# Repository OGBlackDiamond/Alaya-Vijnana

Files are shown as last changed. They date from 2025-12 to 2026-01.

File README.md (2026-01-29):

# Alaya-Vijnana
The hardware and software for my custom split ortholinear column-staggered keyboard
PCB Design Photo
Assembled PCB Photo

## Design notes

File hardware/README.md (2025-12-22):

# Alaya Vijnana Hardware

## B.O.M.
This is a complete B.O.M. for one half of the Alaya Vijnana's PCB components.

MCU:
* nRF52840 - [aQFN73](https://mm.digikey.com/Volume0/opasdata/d220001/medias/docus/6470/NRF52840-QFAA-F-R7.pdf)

Crystal Oscillators:
* 32MHz - [ECX-35B](https://ecsxtal.com/store/pdf/ecx_53b.pdf)
* 32.768kHz - [CM2012H](https://cfd.citizen.co.jp/cms/cfd/pdf/english/CM2012H_E.pdf)

Charger and Power:
* Charger - [BQ24075RGTR](https://www.digikey.com/en/products/detail/texas-instruments/BQ24075RGTR/2047273)
* Voltage Reg - [XC6220B331MR-G](https://www.digikey.com/en/products/detail/torex-semiconductor-ltd/XC6220B331MR-G/2138177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)

Battery Connector:
* JST PH - [S2B-PH-K-S](https://www.digikey.com/en/products/detail/jst-sales-america-inc/S2B-PH-K-S/926626)

Main to Cluster:
* 02x03 Header - 2 - [BHR-06-HUA](https://www.digikey.com/en/products/detail/adam-tech/BHR-06-HUA/10414833)
* Cable - 1 - [371](https://www.digikey.com/en/products/detail/adafruit-industries-llc/371/6827038)

Power Switch:
* E-Switch - [EG1224](https://www.digikey.com/en/products/detail/e-switch/EG1224/502052?s=N4IgTCBcDaIKIHEAEBGMYAsIC6BfIA)

USB-C Connector:
* USB CONN - [USB4085-GF-A](https://www.digikey.com/en/products/detail/gct/USB4085-GF-A/9859662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)

Inductors:
* 10uH - 2 - [MLZ1608M100WTD25](https://www.digikey.com/en/products/detail/tdk-corporation/MLZ1608M100WTD25/4743176)
* 15nH - 1 - [LRC0603CJ15NGV001T](https://www.digikey.com/en/products/detail/johanson-technology-inc/LRC0603CJ15NGV001T/1561308)
* 4.7nH - 1 - [LRC0603CS4N7GV001T](https://www.digikey.com/en/products/detail/johanson-technology-inc/LRC0603CS4N7GV001T/1561296)

LEDs:
* Charge - 1 - [HSMD-C150](https://www.digikey.com/en/products/detail/broadcom-limited/HSMD-C150/637702)

Diodes:
* 21 - [CDSU101A](https://www.digikey.com/en/products/detail/comchip-technology/CDSU101A/1121034)

Hot Swap Sockets:
* 2 (1 = 20pc) - [4958](https://www.digikey.com/en/products/detail/adafruit-industries-llc/4958/13997772)

Resistors:
* 10k - 3 - [RC0603FR-0710KL](https://www.digikey.com/en/products/detail/yageo/RC0603FR-0710KL/726880)
* 10M - 1 - [RC0603JR-0710ML](https://www.digikey.com/en/products/detail/yageo/RC0603JR-0710ML/726701)
* 5.1k - 2 - [RC0603FR-075K1L](https://www.digikey.com/en/products/detail/yageo/RC0603FR-075K1L/727268)
* 2k - 1 - [RC0603JR-072KL](https://www.digikey.com/en/products/detail/yageo/RC0603JR-072KL/726726https://www.digikey.com/en/products/detail/yageo/RC0603JR-072KL/726726)

Capacitors:
* 12pF - 4 - [0603N120J500CT](https://www.digikey.com/en/products/detail/walsin-technology-corporation/0603N120J500CT/9355484)
* 1uF - 3 - [TMK107B7105KA-T](https://www.digikey.com/en/products/detail/taiyo-yuden/TMK107B7105KA-T/2714162)
* 4.7uF - 8 - [C1608X5R1C475K080AC](https://www.digikey.com/en/products/detail/tdk-corporation/C1608X5R1C475K080AC/2732913)
* 0.8pF - 1 - [CC0603BRNPO9BNR80](https://www.digikey.com/en/products/detail/yageo/CC0603BRNPO9BNR80/11490491)
* 0.5pF - 1 - [CBR06C508B5GAC](https://www.digikey.com/en/products/detail/kemet/CBR06C508B5GAC/3473906)
* 10uF - 1 - [LMK107BBJ106MALT](https://www.digikey.com/en/products/detail/taiyo-yuden/LMK107BBJ106MALT/3662195)
* 100pF - 2 - [CC0603JRNPO9BN101](https://www.digikey.com/en/products/detail/yageo/CC0603JRNPO9BN101/302803)
* 820pF - 1 - [CC0603KRX7R9BB821](https://www.digikey.com/en/products/detail/yageo/CC0603KRX7R9BB821/372862)
* 0.047uF - 1 - [CC0603KRX7R8BB473](https://www.digikey.com/en/products/detail/yageo/CC0603KRX7R8BB473/2103111)
* 0.1uF - 3 - [CC0603KRX7R7BB104](https://www.digikey.com/en/products/detail/yageo/CC0603KRX7R7BB104/302822)

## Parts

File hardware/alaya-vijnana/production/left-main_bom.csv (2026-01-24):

Designator | Footprint | Quantity | Value | LCSC Part #
C1, C2, C23, C24 | 0603 | 4 | 12pF
C10, C11 | 0603 | 2 | 100pF
C12 | 0603 | 1 | 820pF
C13, C16, C17, C22, C25, C4, C5 | 0603 | 7 | 4.7uF
C14, C18, C3 | 0603 | 3 | 1uF
C15 | 0603 | 1 | 47nF
C19, C20, C21 | 0603 | 3 | 100nF
C6 | 0603 | 1 | 0.8pF
C7 | 0603 | 1 | 0.5pF
C8 | 0603 | 1 | N.C.
C9 | 0603 | 1 | 10uF
D1, D10, D11, D12, D13, D14, D15, D2, D3, D4, D5, D6, D7, D8, D9 | 0603 | 15 | D
J1 | JST_PH_S2B-PH-K_1x02_P2.00mm_Horizontal | 1 | Bat
J2 | USB_C_Receptacle_GCT_USB4085 | 1 | USB_C_Receptacle_USB2.0_16P
J5 | IDC-Header_2x03_P2.54mm_Horizontal | 1 | MAIN_CONN
L1 | 0402 | 1 | 4.7nH
L2, L4 | 0603 | 2 | 10uH
L3 | 0603 | 1 | 15nH
LED1 | 1206 | 1 | Charge_LED
R1 | 0603 | 1 | 2k
R2, R3, R4 | 0603 | 3 | 10k
R5 | 0603 | 1 | 10M
R6, R7 | 0603 | 2 | 5.1k
SW1 | SW_E-Switch_EG1224_SPDT_Angled | 1 | Power_Switch
SW10, SW11, SW12, SW13, SW14, SW15, SW16, SW2, SW3, SW4, SW5, SW6, SW7, SW8, SW9 | MX-Hotswap-1U | 15 | MX HotSwap
SW45 | SW_Push_1P1T_NO_CK_KMR2 | 1 | SW_Push
TP1 | 2816 | 1 | Charge Boost
U1 | Nordic_AQFN-73-1EP_7x7mm_P0.5mm | 1 | nRF52840
U2 | VQFN-16-1EP_3x3mm_P0.5mm_EP1.6x1.6mm | 1 | BQ24075RGT
U3 | SOT-23-5 | 1 | XC6220B331MR
X1 | Crystal_SMD_2012-2Pin_2.0x1.2mm | 1 | 32.768kHz
Y1 | Crystal_SMD_3225-4Pin_3.2x2.5mm_HandSoldering | 1 | 32Mhz

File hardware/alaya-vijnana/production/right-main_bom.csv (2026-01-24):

Designator | Footprint | Quantity | Value | LCSC Part #
C26, C39, C44 | 0603 | 3 | 1uf
C27, C28, C29 | 0603 | 3 | 100nF
C30, C36, C37, C38, C45, C46, C47 | 0603 | 7 | 4.7uF
C31, C32, C41, C42 | 0603 | 4 | 12pF
C33, C34 | 0603 | 2 | 100pF
C35 | 0603 | 1 | 820pF
C40 | 0603 | 1 | 47nF
C43 | 0603 | 1 | 10uF
C48 | 0603 | 1 | 0.8pF
C49 | 0603 | 1 | 0.5pF
C50 | 0603 | 1 | N.C.
D22, D23, D24, D25, D26, D27, D28, D29, D30, D31, D32, D33, D34, D35, D36 | 0603 | 15 | D
J3 | JST_PH_S2B-PH-K_1x02_P2.00mm_Horizontal | 1 | Bat
J4 | USB_C_Receptacle_GCT_USB4085 | 1 | USB_C_Receptacle_USB2.0_16P
J6 | IDC-Header_2x03_P2.54mm_Horizontal | 1 | MAIN_CONN
L5 | 0603 | 1 | 15nH
L6, L7 | 0603 | 2 | 10uH
L8 | 0402 | 1 | 4.7nH
LED2 | 1206 | 1 | Charge_LED
R10 | 0603 | 1 | 10M
R11, R12, R9 | 0603 | 3 | 10k
R13, R14 | 0603 | 2 | 5.1k
R8 | 0603 | 1 | 2k
SW24, SW25, SW26, SW27, SW28, SW29, SW30, SW31, SW32, SW33, SW34, SW35, SW36, SW37, SW38 | MX-Hotswap-1U | 15 | MX HotSwap
SW46 | SW_Push_1P1T_NO_CK_KMR2 | 1 | SW_Push
TP2 | 2816 | 1 | Charge Boost
U4 | Nordic_AQFN-73-1EP_7x7mm_P0.5mm | 1 | nRF52840
U5 | SOT-23-5 | 1 | XC6220B331MR
U6 | VQFN-16-1EP_3x3mm_P0.5mm_EP1.6x1.6mm | 1 | BQ24075RGT
X2 | Crystal_SMD_2012-2Pin_2.0x1.2mm | 1 | 32.768kHz
Y2 | Crystal_SMD_3225-4Pin_3.2x2.5mm_HandSoldering | 1 | 32Mhz

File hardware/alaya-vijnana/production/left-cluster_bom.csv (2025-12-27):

Designator | Footprint | Quantity | Value | LCSC Part #
D16, D17, D18, D19, D20, D21 | 0603 | 6 | D
J8 | IDC-Header_2x03_P2.54mm_Horizontal | 1 | CLUSTER_CONN
SW17, SW20, SW21, SW22 | MX-Hotswap-1U | 4 | MX HotSwap
SW18, SW19 | MX-Hotswap-2U | 2 | MX HotSwap

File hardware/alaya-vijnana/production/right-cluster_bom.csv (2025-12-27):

Designator | Footprint | Quantity | Value | LCSC Part #
D37, D38, D39, D40, D41, D42 | 0603 | 6 | D
J7 | IDC-Header_2x03_P2.54mm_Horizontal | 1 | CLUSTER_CONN
SW39, SW42, SW43, SW44 | MX-Hotswap-1U | 4 | MX HotSwap
SW40, SW41 | MX-Hotswap-2U | 2 | MX HotSwap

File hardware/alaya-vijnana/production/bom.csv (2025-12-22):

Designator | Footprint | Quantity | Value | LCSC Part #
C1, C2, C23, C24, C31, C32, C41, C42 | 0603 | 8 | 12pF
C10, C11, C33, C34 | 0603 | 4 | 100pF
C12, C35 | 0603 | 2 | 820pF
C13, C16, C17, C22, C25, C30, C36, C37, C38, C4, C45, C46, C47, C5 | 0603 | 14 | 4.7uF
C14, C18, C26, C3, C39, C44 | 0603 | 6 | 1uF
C15, C40 | 0603 | 2 | 47nF
C19, C20, C21, C27, C28, C29 | 0603 | 6 | 100nF
C43, C9 | 0603 | 2 | 10uF
C48, C6 | 0603 | 2 | 0.8pF
C49, C7 | 0603 | 2 | 0.5pF
C50, C8 | 0603 | 2 | N.C.
D1, D10, D11, D12, D13, D14, D15, D16, D17, D18, D19, D2, D20, D21, D22, D23, D24, D25, D26, D27, D28, D29, D3, D30, D31, D32, D33, D34, D35, D36, D37, D38, D39, D4, D40, D41, D42, D5, D6, D7, D8, D9 | 0603 | 42 | D
J1, J3 | JST_PH_S2B-PH-K_1x02_P2.00mm_Horizontal | 2 | Bat
J2, J4 | USB_C_Receptacle_GCT_USB4085 | 2 | USB_C_Receptacle_USB2.0_16P
J5, J6 | IDC-Header_2x03_P2.54mm_Horizontal | 2 | MAIN_CONN
J7, J8 | IDC-Header_2x03_P2.54mm_Horizontal | 2 | CLUSTER_CONN
L1, L8 | 0402 | 2 | 4.7nH
L2, L4, L6, L7 | 0603 | 4 | 10uH
L3, L5 | 0603 | 2 | 15nH
LED1, LED2 | 1206 | 2 | Charge_LED
R1, R8 | 0603 | 2 | 2k
R10, R5 | 0603 | 2 | 10M
R11, R12, R2, R3, R4, R9 | 0603 | 6 | 10k
R13, R14, R6, R7 | 0603 | 4 | 5.1k
SW1, SW23 | SW_E-Switch_EG1224_SPDT_Angled | 2 | Power_Switch
SW10, SW11, SW12, SW13, SW14, SW15, SW16, SW17, SW2, SW20, SW21, SW22, SW24, SW25, SW26, SW27, SW28, SW29, SW3, SW30, SW31, SW32, SW33, SW34, SW35, SW36, SW37, SW38, SW39, SW4, SW42, SW43, SW44, SW5, SW6, SW7, SW8, SW9 | MX-Hotswap-1U | 38 | MX HotSwap
SW18, SW19, SW40, SW41 | MX-Hotswap-2U | 4 | MX HotSwap
TP1, TP2 | 2816 | 2 | Charge Boost
U1, U4 | Nordic_AQFN-73-1EP_7x7mm_P0.5mm | 2 | nRF52840
U2, U6 | VQFN-16-1EP_3x3mm_P0.5mm_EP1.6x1.6mm | 2 | BQ24075RGT
U3, U5 | SOT-23-5 | 2 | XC6220B331MR
X1, X2 | Crystal_SMD_2012-2Pin_2.0x1.2mm | 2 | 32.768kHz
Y1, Y2 | Crystal_SMD_3225-4Pin_3.2x2.5mm_HandSoldering | 2 | 32Mhz

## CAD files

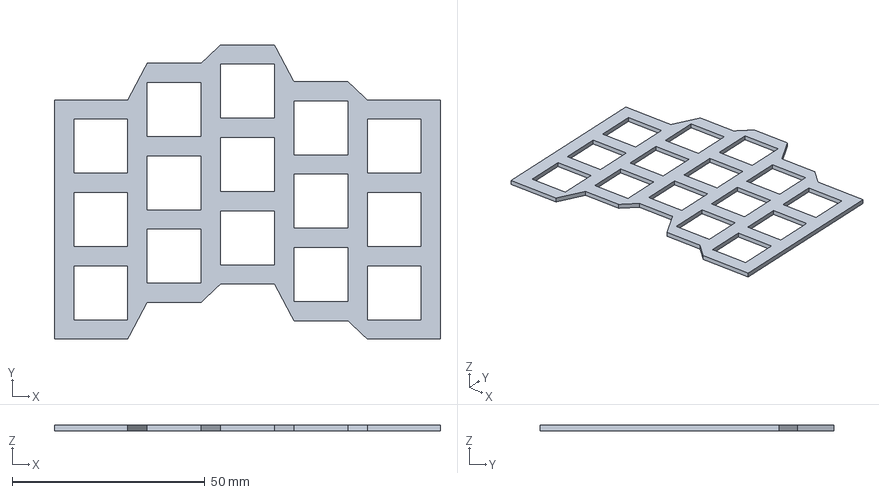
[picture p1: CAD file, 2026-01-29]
hardware/CAD/left-main.FCStd
100.2 x 76.4 x 1.50 mm

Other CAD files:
hardware/CAD/left-main.stl

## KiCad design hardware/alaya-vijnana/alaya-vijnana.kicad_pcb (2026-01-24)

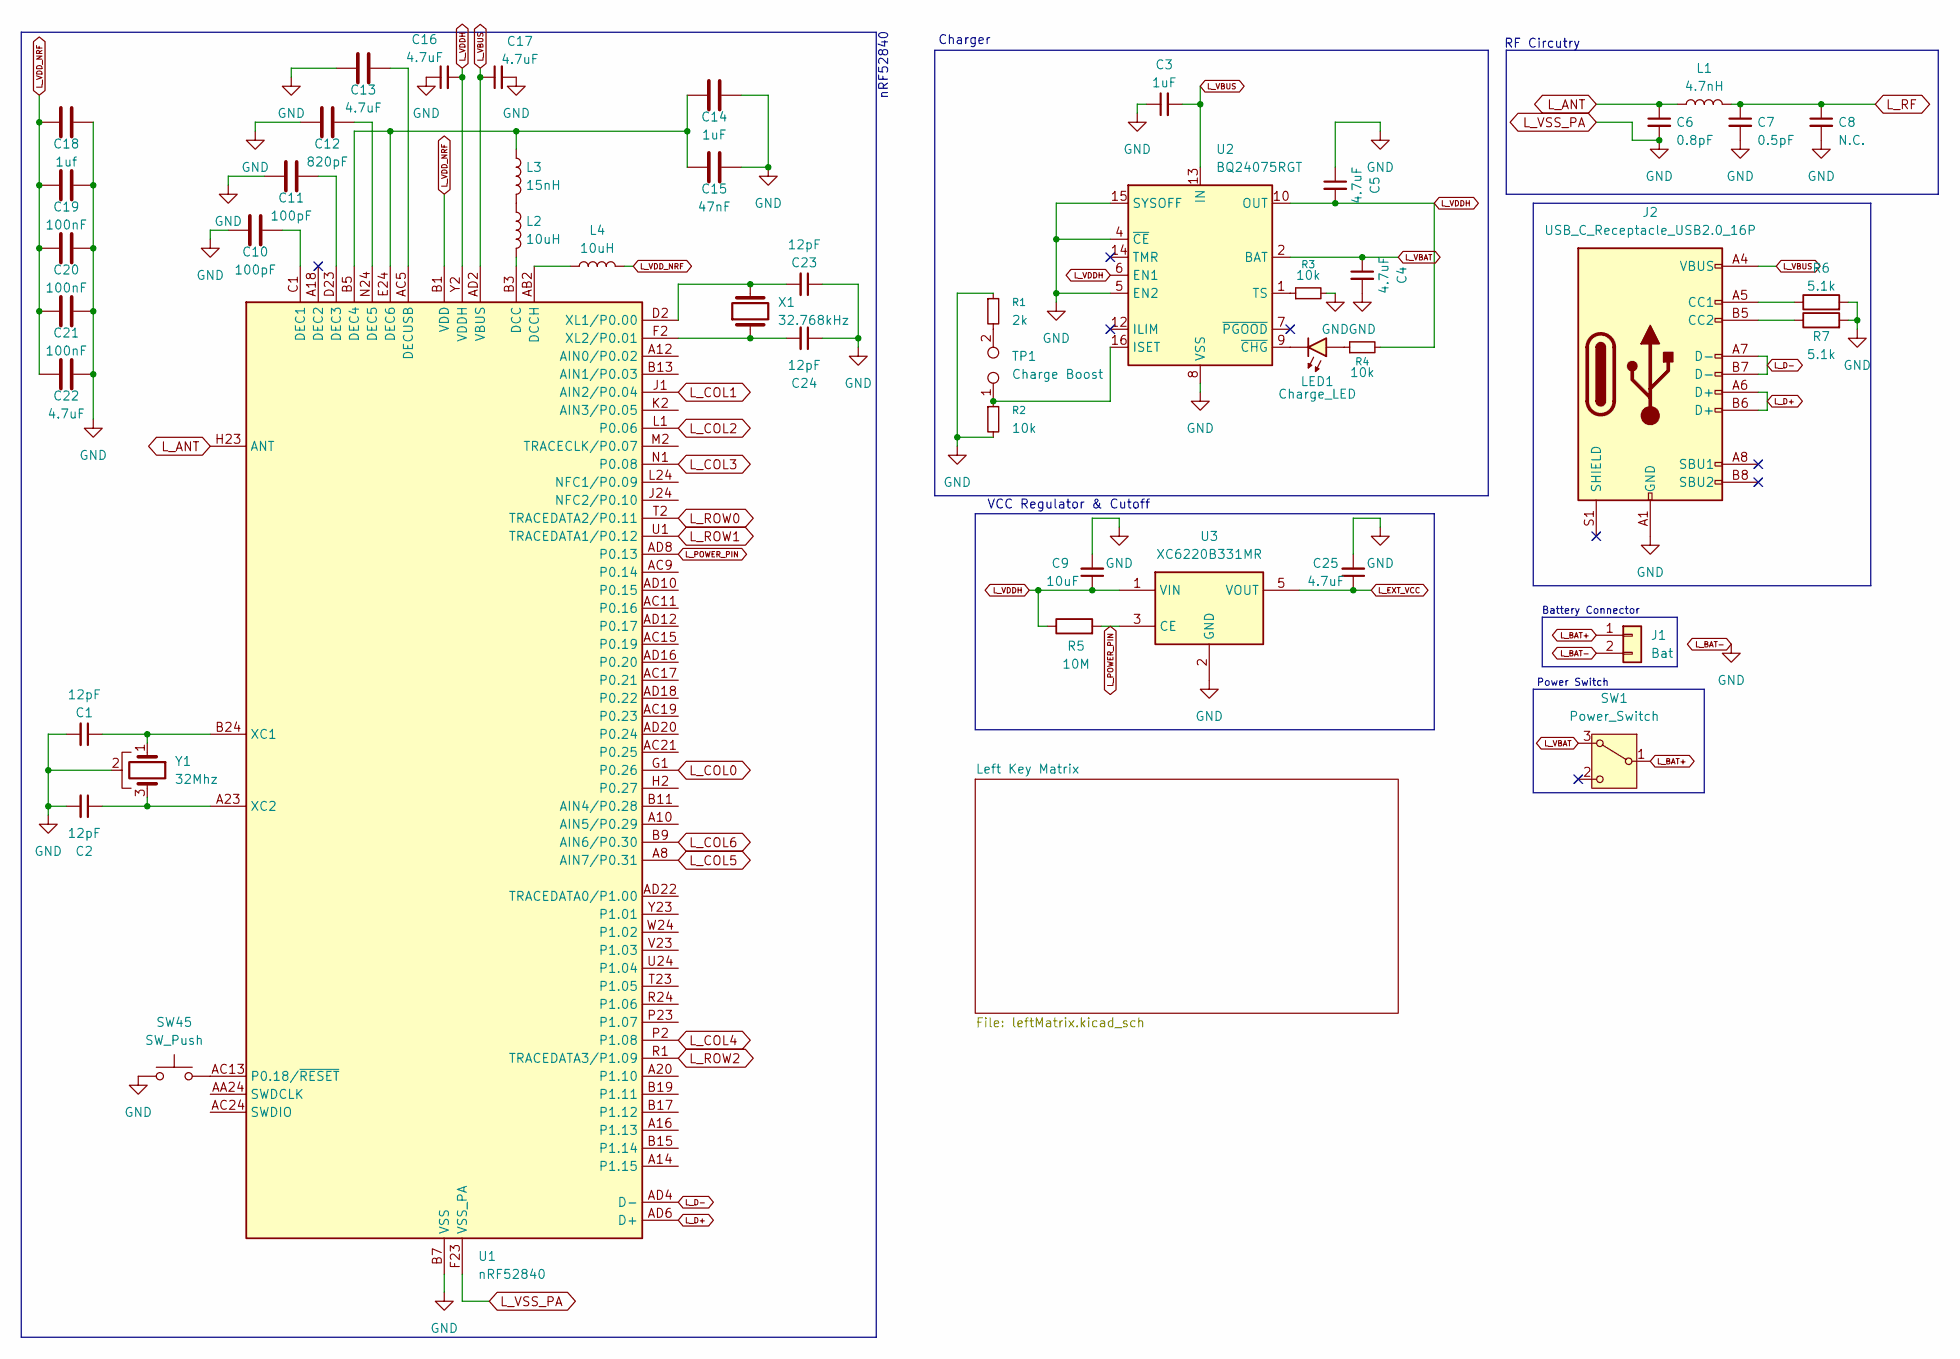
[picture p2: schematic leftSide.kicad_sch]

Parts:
C1, C2, C23, C24: 12pF; C_0603_1608Metric_Pad1.08x0.95mm_HandSolder
C3, C14: 1uF; C_0603_1608Metric_Pad1.08x0.95mm_HandSolder
C4, C5, C13, C16, C17, C22, C25: 4.7uF; C_0603_1608Metric_Pad1.08x0.95mm_HandSolder
C6: 0.8pF; C_0603_1608Metric_Pad1.08x0.95mm_HandSolder
C7: 0.5pF; C_0603_1608Metric_Pad1.08x0.95mm_HandSolder
C8: N.C.; C_0603_1608Metric_Pad1.08x0.95mm_HandSolder
C9: 10uF; C_0603_1608Metric_Pad1.08x0.95mm_HandSolder
C10, C11: 100pF; C_0603_1608Metric_Pad1.08x0.95mm_HandSolder
C12: 820pF; C_0603_1608Metric_Pad1.08x0.95mm_HandSolder
C15: 47nF; C_0603_1608Metric_Pad1.08x0.95mm_HandSolder
C18: 1uf; C_0603_1608Metric_Pad1.08x0.95mm_HandSolder
C19, C20, C21: 100nF; C_0603_1608Metric_Pad1.08x0.95mm_HandSolder
J1: Bat; JST_PH_S2B-PH-K_1x02_P2.00mm_Horizontal
J2: USB_C_Receptacle_USB2.0_16P; USB_C_Receptacle_GCT_USB4085
L1: 4.7nH; L_0402_1005Metric_Pad0.77x0.64mm_HandSolder
L2, L4: 10uH; L_0603_1608Metric
L3: 15nH; L_0603_1608Metric
LED1: Charge_LED; LED_1206_3216Metric
R1: 2k; R_0603_1608Metric_Pad0.98x0.95mm_HandSolder
R2, R3, R4: 10k; R_0603_1608Metric_Pad0.98x0.95mm_HandSolder
R5: 10M; R_0603_1608Metric_Pad0.98x0.95mm_HandSolder
R6, R7: 5.1k; R_0603_1608Metric_Pad0.98x0.95mm_HandSolder
SW1: Power_Switch; SW_E-Switch_EG1224_SPDT_Angled
SW45: SW_Push; SW_Push_1P1T_NO_CK_KMR2
TP1: Charge Boost; R_2816_7142Metric_Pad3.20x4.45mm_HandSolder
U1: nRF52840; Nordic_AQFN-73-1EP_7x7mm_P0.5mm
U2: BQ24075RGT; VQFN-16-1EP_3x3mm_P0.5mm_EP1.6x1.6mm
U3: XC6220B331MR; SOT-23-5
X1: 32.768kHz; Crystal_SMD_2012-2Pin_2.0x1.2mm
Y1: 32Mhz; Crystal_SMD_3225-4Pin_3.2x2.5mm_HandSoldering

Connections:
L_ANT: C6.1, L1.1, U1.H23 (ANT)
L_BAT+: J1.1, SW1.1 (B)
L_BAT-: C1.2, C2.2, C3.1, C4.2, C5.1, C6.2, C7.2, C8.2, C9.2, C10.1, C11.1, C12.1, C13.1, C14.2, C15.2, C16.1, C17.2, C18.2, C19.2, C20.2, C21.2, C22.2, C23.1, C24.1, C25.2, J1.2, J2.A1 (GND), J2.A12 (GND), J2.B1 (GND), J2.B12 (GND), R1.1, R2.2, R3.2, R6.2, R7.2, SW45.1, U1.B7 (VSS), U1.EP (VSS), U1.F23 (VSS_PA), U2.4 (~CE), U2.5 (EN2), U2.8 (VSS), U2.15 (SYSOFF), U2.17 (VSS), U3.2 (GND), Y1.2; also elsewhere on the board
L_COL0: U1.G1 (P0.26); also elsewhere on the board
L_COL1: U1.J1 (AIN2/P0.04); also elsewhere on the board
L_COL2: U1.L1 (P0.06); also elsewhere on the board
L_COL3: U1.N1 (P0.08); also elsewhere on the board
L_COL4: U1.P2 (P1.08); also elsewhere on the board
L_COL5: U1.A8 (AIN7/P0.31); also elsewhere on the board
L_COL6: U1.B9 (AIN6/P0.30); also elsewhere on the board
L_D+: J2.A6 (D+), J2.B6 (D+), U1.AD6 (D+)
L_D-: J2.A7 (D-), J2.B7 (D-), U1.AD4 (D-)
L_EXT_VCC: C25.1, U3.5 (VOUT)
L_POWER_PIN: R5.2, U1.AD8 (P0.13), U3.3 (CE)
L_RF: C7.1, C8.1, L1.2
L_ROW0: U1.T2 (TRACEDATA2/P0.11); also elsewhere on the board
L_ROW1: U1.U1 (TRACEDATA1/P0.12); also elsewhere on the board
L_ROW2: U1.R1 (TRACEDATA3/P1.09); also elsewhere on the board
L_VBAT: C4.1, SW1.3 (A), U2.2 (BAT), U2.3 (BAT)
L_VBUS: C3.2, C17.1, J2.A4 (VBUS), J2.A9 (VBUS), J2.B4 (VBUS), J2.B9 (VBUS), U1.AD2 (VBUS), U2.13 (IN)
L_VDDH: C5.2, C9.1, C16.2, R4.2, R5.1, U1.Y2 (VDDH), U2.6 (EN1), U2.10 (OUT), U2.11 (OUT), U3.1 (VIN)
L_VDD_NRF: C18.1, C19.1, C20.1, C21.1, C22.1, L4.2, U1.A22 (VDD), U1.AD14 (VDD), U1.AD23 (VDD), U1.B1 (VDD), U1.W1 (VDD)
unnamed: J2.A5 (CC1), R6.1
unnamed: J2.B5 (CC2), R7.1
unnamed: L2.1, L3.2
unnamed: LED1.2 (A), R4.1
unnamed: LED1.1 (K), U2.9 (~CHG)
unnamed: R1.2, TP1.2
unnamed: L2.2, U1.B3 (DCC)
unnamed: L4.1, U1.AB2 (DCCH)
unnamed: C10.2, U1.C1 (DEC1)
unnamed: C11.2, U1.D23 (DEC3)
unnamed: C14.1, C15.1, L3.1, U1.B5 (DEC4), U1.E24 (DEC6)
unnamed: C12.2, U1.N24 (DEC5)
unnamed: C13.2, U1.AC5 (DECUSB)
unnamed: SW45.2, U1.AC13 (P0.18/~RESET)
unnamed: C1.1, U1.B24 (XC1), Y1.1
unnamed: C2.1, U1.A23 (XC2), Y1.3
unnamed: C23.2, U1.D2 (XL1/P0.00), X1.2
unnamed: C24.2, U1.F2 (XL2/P0.01), X1.1
unnamed: R2.1, TP1.1, U2.16 (ISET)
unnamed: R3.1, U2.1 (TS)

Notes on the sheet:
Charger
nRF52840
RF Circutry
Power Switch
VCC Regulator & Cutoff
Battery Connector

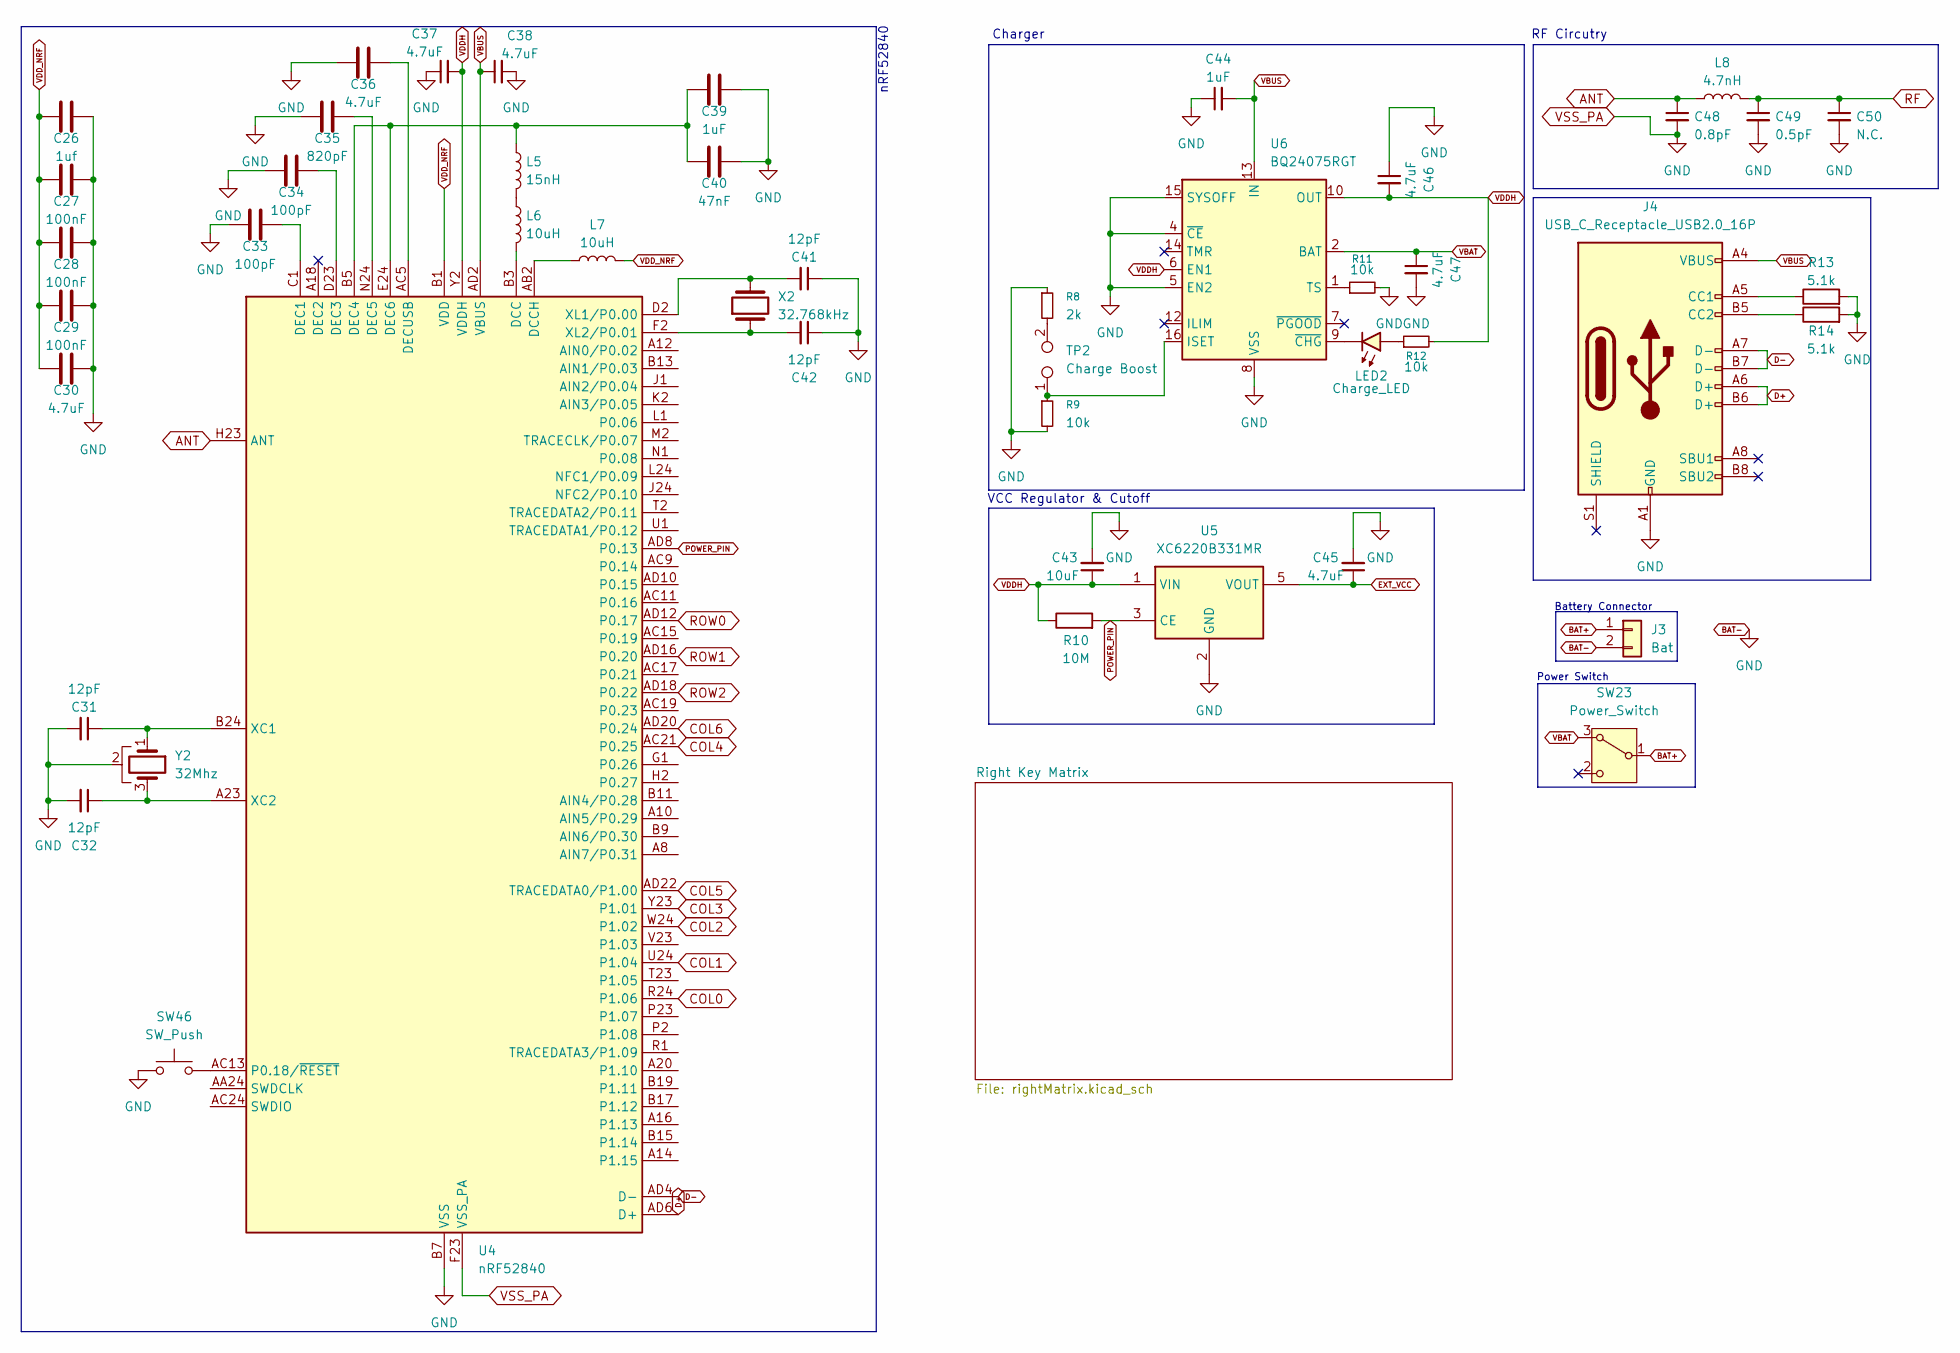
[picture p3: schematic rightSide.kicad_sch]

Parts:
C26: 1uf; C_0603_1608Metric_Pad1.08x0.95mm_HandSolder
C27, C28, C29: 100nF; C_0603_1608Metric_Pad1.08x0.95mm_HandSolder
C30, C36, C37, C38, C45, C46, C47: 4.7uF; C_0603_1608Metric_Pad1.08x0.95mm_HandSolder
C31, C32, C41, C42: 12pF; C_0603_1608Metric_Pad1.08x0.95mm_HandSolder
C33, C34: 100pF; C_0603_1608Metric_Pad1.08x0.95mm_HandSolder
C35: 820pF; C_0603_1608Metric_Pad1.08x0.95mm_HandSolder
C39, C44: 1uF; C_0603_1608Metric_Pad1.08x0.95mm_HandSolder
C40: 47nF; C_0603_1608Metric_Pad1.08x0.95mm_HandSolder
C43: 10uF; C_0603_1608Metric_Pad1.08x0.95mm_HandSolder
C48: 0.8pF; C_0603_1608Metric_Pad1.08x0.95mm_HandSolder
C49: 0.5pF; C_0603_1608Metric_Pad1.08x0.95mm_HandSolder
C50: N.C.; C_0603_1608Metric_Pad1.08x0.95mm_HandSolder
J3: Bat; JST_PH_S2B-PH-K_1x02_P2.00mm_Horizontal
J4: USB_C_Receptacle_USB2.0_16P; USB_C_Receptacle_GCT_USB4085
L5: 15nH; L_0603_1608Metric
L6, L7: 10uH; L_0603_1608Metric
L8: 4.7nH; L_0402_1005Metric_Pad0.77x0.64mm_HandSolder
LED2: Charge_LED; LED_1206_3216Metric
R8: 2k; R_0603_1608Metric_Pad0.98x0.95mm_HandSolder
R9, R11, R12: 10k; R_0603_1608Metric_Pad0.98x0.95mm_HandSolder
R10: 10M; R_0603_1608Metric_Pad0.98x0.95mm_HandSolder
R13, R14: 5.1k; R_0603_1608Metric_Pad0.98x0.95mm_HandSolder
SW23: Power_Switch; SW_E-Switch_EG1224_SPDT_Angled
SW46: SW_Push; SW_Push_1P1T_NO_CK_KMR2
TP2: Charge Boost; R_2816_7142Metric_Pad3.20x4.45mm_HandSolder
U4: nRF52840; Nordic_AQFN-73-1EP_7x7mm_P0.5mm
U5: XC6220B331MR; SOT-23-5
U6: BQ24075RGT; VQFN-16-1EP_3x3mm_P0.5mm_EP1.6x1.6mm
X2: 32.768kHz; Crystal_SMD_2012-2Pin_2.0x1.2mm
Y2: 32Mhz; Crystal_SMD_3225-4Pin_3.2x2.5mm_HandSoldering

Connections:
ANT: C48.1, L8.1, U4.H23 (ANT)
BAT+: J3.1, SW23.1 (B)
COL0: U4.R24 (P1.06); also elsewhere on the board
COL1: U4.U24 (P1.04); also elsewhere on the board
COL2: U4.W24 (P1.02); also elsewhere on the board
COL3: U4.Y23 (P1.01); also elsewhere on the board
COL4: U4.AC21 (P0.25); also elsewhere on the board
COL5: U4.AD22 (TRACEDATA0/P1.00); also elsewhere on the board
COL6: U4.AD20 (P0.24); also elsewhere on the board
D+: J4.A6 (D+), J4.B6 (D+), U4.AD6 (D+)
D-: J4.A7 (D-), J4.B7 (D-), U4.AD4 (D-)
EXT_VCC: C45.1, U5.5 (VOUT)
L_BAT-: C26.2, C27.2, C28.2, C29.2, C30.2, C31.2, C32.2, C33.1, C34.1, C35.1, C36.1, C37.1, C38.2, C39.2, C40.2, C41.1, C42.1, C43.2, C44.1, C45.2, C46.1, C47.2, C48.2, C49.2, C50.2, J3.2, J4.A1 (GND), J4.A12 (GND), J4.B1 (GND), J4.B12 (GND), R8.1, R9.2, R11.2, R13.2, R14.2, SW46.1, U4.B7 (VSS), U4.EP (VSS), U4.F23 (VSS_PA), U5.2 (GND), U6.4 (~CE), U6.5 (EN2), U6.8 (VSS), U6.15 (SYSOFF), U6.17 (VSS), Y2.2; also elsewhere on the board
unnamed: J4.A5 (CC1), R13.1
unnamed: J4.B5 (CC2), R14.1
unnamed: L5.2, L6.1
unnamed: LED2.2 (A), R12.1
unnamed: LED2.1 (K), U6.9 (~CHG)
unnamed: R8.2, TP2.2
unnamed: L6.2, U4.B3 (DCC)
unnamed: L7.1, U4.AB2 (DCCH)
unnamed: C33.2, U4.C1 (DEC1)
unnamed: C34.2, U4.D23 (DEC3)
unnamed: C39.1, C40.1, L5.1, U4.B5 (DEC4), U4.E24 (DEC6)
unnamed: C35.2, U4.N24 (DEC5)
unnamed: C36.2, U4.AC5 (DECUSB)
unnamed: SW46.2, U4.AC13 (P0.18/~RESET)
unnamed: C31.1, U4.B24 (XC1), Y2.1
unnamed: C32.1, U4.A23 (XC2), Y2.3
unnamed: C41.2, U4.D2 (XL1/P0.00), X2.2
unnamed: C42.2, U4.F2 (XL2/P0.01), X2.1
unnamed: R9.1, TP2.1, U6.16 (ISET)
unnamed: R11.1, U6.1 (TS)
POWER_PIN: R10.2, U4.AD8 (P0.13), U5.3 (CE)
RF: C49.1, C50.1, L8.2
ROW0: U4.AD12 (P0.17); also elsewhere on the board
ROW1: U4.AD16 (P0.20); also elsewhere on the board
ROW2: U4.AD18 (P0.22); also elsewhere on the board
VBAT: C47.1, SW23.3 (A), U6.2 (BAT), U6.3 (BAT)
VBUS: C38.1, C44.2, J4.A4 (VBUS), J4.A9 (VBUS), J4.B4 (VBUS), J4.B9 (VBUS), U4.AD2 (VBUS), U6.13 (IN)
VDDH: C37.2, C43.1, C46.2, R10.1, R12.2, U4.Y2 (VDDH), U5.1 (VIN), U6.6 (EN1), U6.10 (OUT), U6.11 (OUT)
VDD_NRF: C26.1, C27.1, C28.1, C29.1, C30.1, L7.2, U4.A22 (VDD), U4.AD14 (VDD), U4.AD23 (VDD), U4.B1 (VDD), U4.W1 (VDD)

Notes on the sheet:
Charger
Battery Connector
VCC Regulator & Cutoff
Power Switch
nRF52840
RF Circutry

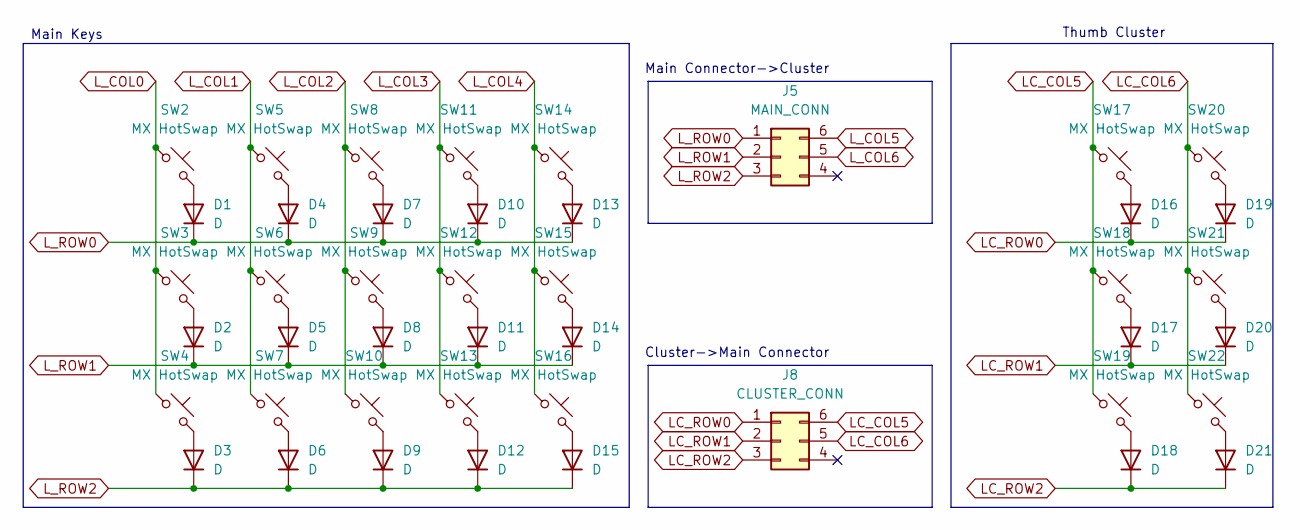
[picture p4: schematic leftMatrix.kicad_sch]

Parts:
D1, D2, D3, D4, D5, D6, D7, D8, D9, D10, D11, D12, D13, D14, D15, D16, D17, D18, D19, D20, D21: D; D_0603_1608Metric_Pad1.05x0.95mm_HandSolder
J5: MAIN_CONN; IDC-Header_2x03_P2.54mm_Horizontal
J8: CLUSTER_CONN; IDC-Header_2x03_P2.54mm_Horizontal
SW2, SW3, SW4, SW5, SW6, SW7, SW8, SW9, SW10, SW11, SW12, SW13, SW14, SW15, SW16, SW17, SW20, SW21, SW22: MX HotSwap; MX-Hotswap-1U
SW18, SW19: MX HotSwap; MX-Hotswap-2U

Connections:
LC_COL5: J8.6, SW17.1, SW18.1, SW19.1
LC_COL6: J8.5, SW20.1, SW21.1, SW22.1
LC_ROW0: D16.1 (K), D19.1 (K), J8.1
LC_ROW1: D17.1 (K), D20.1 (K), J8.2
LC_ROW2: D18.1 (K), D21.1 (K), J8.3
L_COL0: SW2.1, SW3.1, SW4.1; also elsewhere on the board
L_COL1: SW5.1, SW6.1, SW7.1; also elsewhere on the board
L_COL2: SW8.1, SW9.1, SW10.1; also elsewhere on the board
L_COL3: SW11.1, SW12.1, SW13.1; also elsewhere on the board
L_COL4: SW14.1, SW15.1, SW16.1; also elsewhere on the board
L_COL5: J5.6; also elsewhere on the board
L_COL6: J5.5; also elsewhere on the board
L_ROW0: D1.1 (K), D4.1 (K), D7.1 (K), D10.1 (K), D13.1 (K), J5.1; also elsewhere on the board
L_ROW1: D2.1 (K), D5.1 (K), D8.1 (K), D11.1 (K), D14.1 (K), J5.2; also elsewhere on the board
L_ROW2: D3.1 (K), D6.1 (K), D9.1 (K), D12.1 (K), D15.1 (K), J5.3; also elsewhere on the board
unnamed: D1.2 (A), SW2.2
unnamed: D2.2 (A), SW3.2
unnamed: D3.2 (A), SW4.2
unnamed: D4.2 (A), SW5.2
unnamed: D5.2 (A), SW6.2
unnamed: D6.2 (A), SW7.2
unnamed: D7.2 (A), SW8.2
unnamed: D8.2 (A), SW9.2
unnamed: D9.2 (A), SW10.2
unnamed: D10.2 (A), SW11.2
unnamed: D11.2 (A), SW12.2
unnamed: D12.2 (A), SW13.2
unnamed: D13.2 (A), SW14.2
unnamed: D14.2 (A), SW15.2
unnamed: D15.2 (A), SW16.2
unnamed: D16.2 (A), SW17.2
unnamed: D17.2 (A), SW18.2
unnamed: D18.2 (A), SW19.2
unnamed: D19.2 (A), SW20.2
unnamed: D20.2 (A), SW21.2
unnamed: D21.2 (A), SW22.2

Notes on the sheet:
Cluster->Main Connector
Thumb Cluster
Main Keys
Main Connector->Cluster

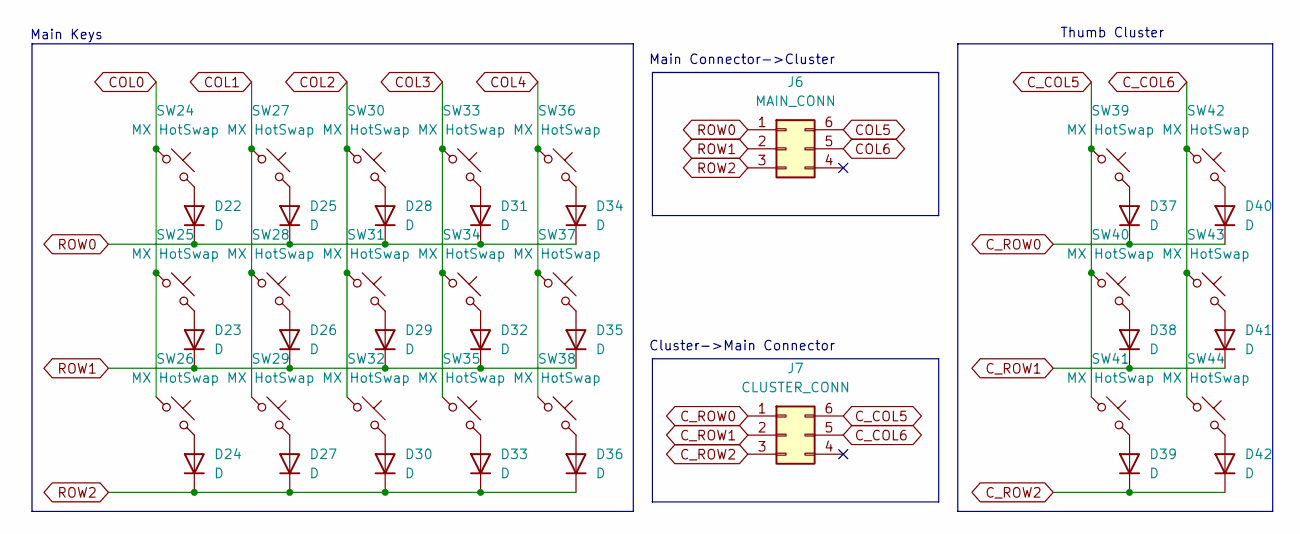
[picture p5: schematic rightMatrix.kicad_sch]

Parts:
D22, D23, D24, D25, D26, D27, D28, D29, D30, D31, D32, D33, D34, D35, D36, D37, D38, D39, D40, D41, D42: D; D_0603_1608Metric_Pad1.05x0.95mm_HandSolder
J6: MAIN_CONN; IDC-Header_2x03_P2.54mm_Horizontal
J7: CLUSTER_CONN; IDC-Header_2x03_P2.54mm_Horizontal
SW24, SW25, SW26, SW27, SW28, SW29, SW30, SW31, SW32, SW33, SW34, SW35, SW36, SW37, SW38, SW39, SW42, SW43, SW44: MX HotSwap; MX-Hotswap-1U
SW40, SW41: MX HotSwap; MX-Hotswap-2U

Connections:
COL0: SW24.1, SW25.1, SW26.1; also elsewhere on the board
COL1: SW27.1, SW28.1, SW29.1; also elsewhere on the board
COL2: SW30.1, SW31.1, SW32.1; also elsewhere on the board
COL3: SW33.1, SW34.1, SW35.1; also elsewhere on the board
COL4: SW36.1, SW37.1, SW38.1; also elsewhere on the board
COL5: J6.6; also elsewhere on the board
COL6: J6.5; also elsewhere on the board
C_COL5: J7.6, SW39.1, SW40.1, SW41.1
C_COL6: J7.5, SW42.1, SW43.1, SW44.1
C_ROW0: D37.1 (K), D40.1 (K), J7.1
C_ROW1: D38.1 (K), D41.1 (K), J7.2
C_ROW2: D39.1 (K), D42.1 (K), J7.3
unnamed: D22.2 (A), SW24.2
unnamed: D23.2 (A), SW25.2
unnamed: D24.2 (A), SW26.2
unnamed: D25.2 (A), SW27.2
unnamed: D26.2 (A), SW28.2
unnamed: D27.2 (A), SW29.2
unnamed: D28.2 (A), SW30.2
unnamed: D29.2 (A), SW31.2
unnamed: D30.2 (A), SW32.2
unnamed: D31.2 (A), SW33.2
unnamed: D32.2 (A), SW34.2
unnamed: D33.2 (A), SW35.2
unnamed: D34.2 (A), SW36.2
unnamed: D35.2 (A), SW37.2
unnamed: D36.2 (A), SW38.2
unnamed: D37.2 (A), SW39.2
unnamed: D38.2 (A), SW40.2
unnamed: D39.2 (A), SW41.2
unnamed: D40.2 (A), SW42.2
unnamed: D41.2 (A), SW43.2
unnamed: D42.2 (A), SW44.2
ROW0: D22.1 (K), D25.1 (K), D28.1 (K), D31.1 (K), D34.1 (K), J6.1; also elsewhere on the board
ROW1: D23.1 (K), D26.1 (K), D29.1 (K), D32.1 (K), D35.1 (K), J6.2; also elsewhere on the board
ROW2: D24.1 (K), D27.1 (K), D30.1 (K), D33.1 (K), D36.1 (K), J6.3; also elsewhere on the board

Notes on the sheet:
Main Keys
Cluster->Main Connector
Main Connector->Cluster
Thumb Cluster

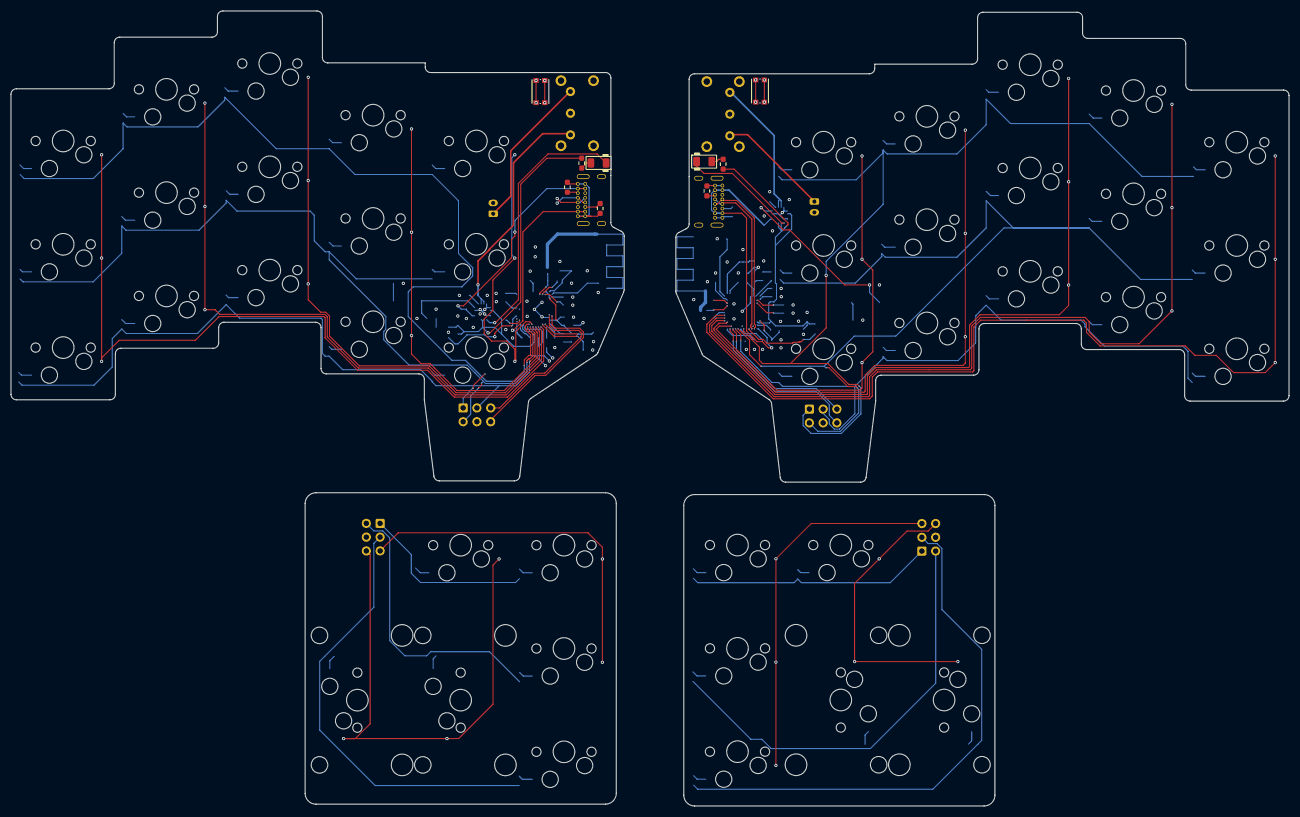
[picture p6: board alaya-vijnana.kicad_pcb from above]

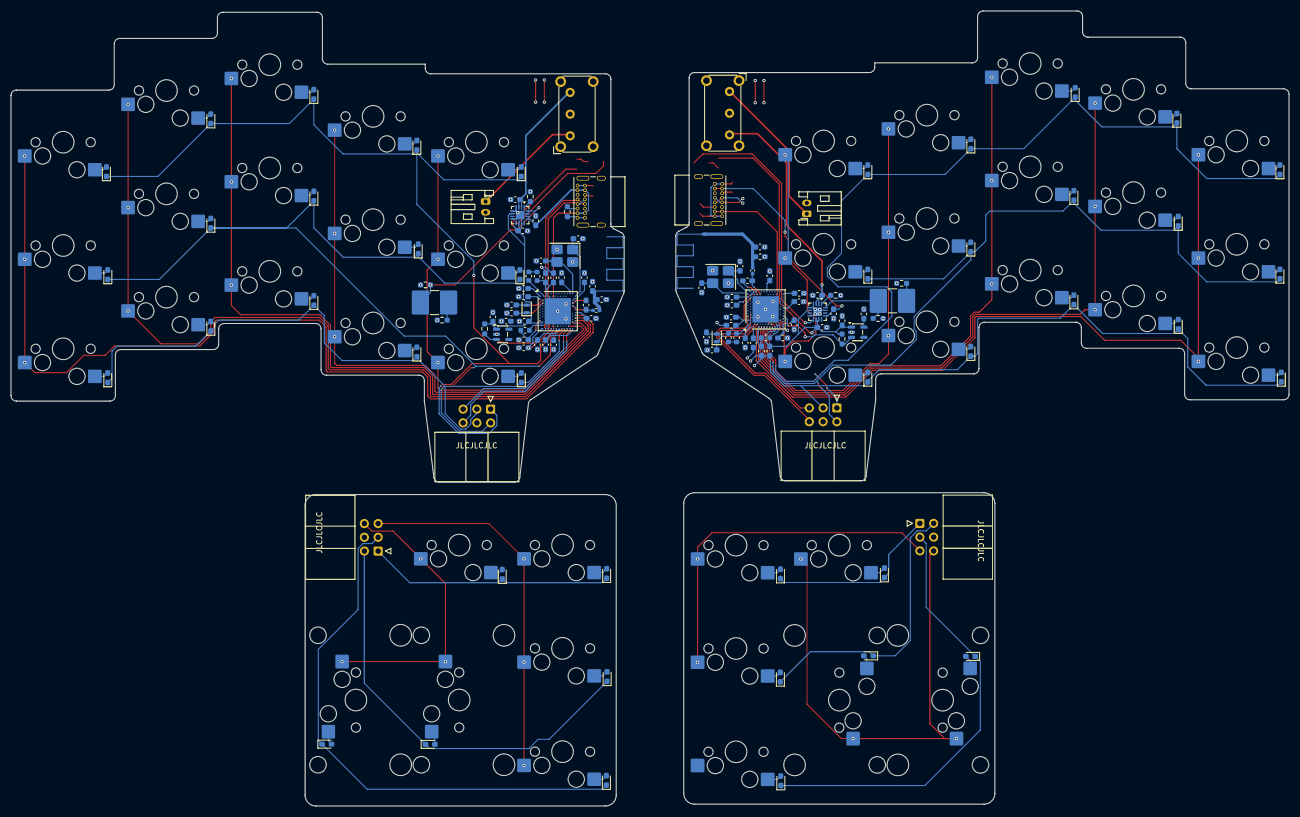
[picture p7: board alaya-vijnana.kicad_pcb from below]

Board: 4 copper layers, 235.7 x 146.6 mm, 182 parts (173 on the bottom side), 135 nets.

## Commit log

2025-12-19 made left half
    [alaya-vijnana.kicad_pcb, alaya-vijnana.kicad_sch, leftSide.kicad_sch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]
2025-12-19 schematics done outside of cluster to main connectors, PCB laid out
    [alaya-vijnana.kicad_pcb, leftMatrix.kicad_sch, leftSide.kicad_sch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]
2025-12-19 finished key wiring w/ connectors
    [alaya-vijnana.kicad_pcb, leftMatrix.kicad_sch, leftSide.kicad_sch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]
2025-12-19 added pcb antenna
    [alaya-vijnana.kicad_pcb]
2025-12-21 left side wired up
    [alaya-vijnana.kicad_pcb, alaya-vijnana.kicad_sch, leftSide.kicad_sch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]
2025-12-22 fixed everything
    [alaya-vijnana.kicad_pcb]
2025-12-27 split into parts
    [alaya-vijnana.kicad_pcb, left-cluster.kicad_pcb, left-cluster_bom.csv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]
2026-01-07 added firmware
    [left-main.kicad_pcb, right-main.kicad_pcb]
2026-01-24 production stuff
    [alaya-vijnana.kicad_pcb, left-cluster.kicad_pcb, left-cluster_positions.csv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]
2026-01-26 added 3d model
    [main.FCStd]
2026-01-26 more correct
    [main.FCStd]
2026-01-29 finished left main plate
    [left-main.FCStd, main.FCStd]
2026-01-29 corrected cad
    [left-main.FCStd, left-main.stl]
